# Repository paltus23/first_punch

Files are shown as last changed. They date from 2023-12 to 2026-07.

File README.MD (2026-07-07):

This project is intedent to sinmplify start teaching electronics for musical sysntesizers. 

I've already assempled and tested versions 1 and 1.1. 
Version 1.1 works fine but have two issues.
* You should cut track which connects gnd and pin 1 of RV10. Then you should solder small wire between RV10 pin 1 and Vref node.
* There is wrong ploarity of power supply

To use project install Kode Mono font.

There is few photos of ready device v1.1
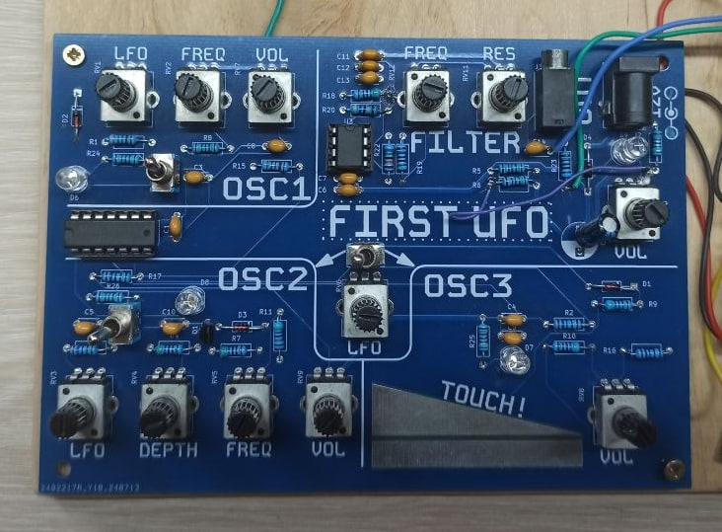
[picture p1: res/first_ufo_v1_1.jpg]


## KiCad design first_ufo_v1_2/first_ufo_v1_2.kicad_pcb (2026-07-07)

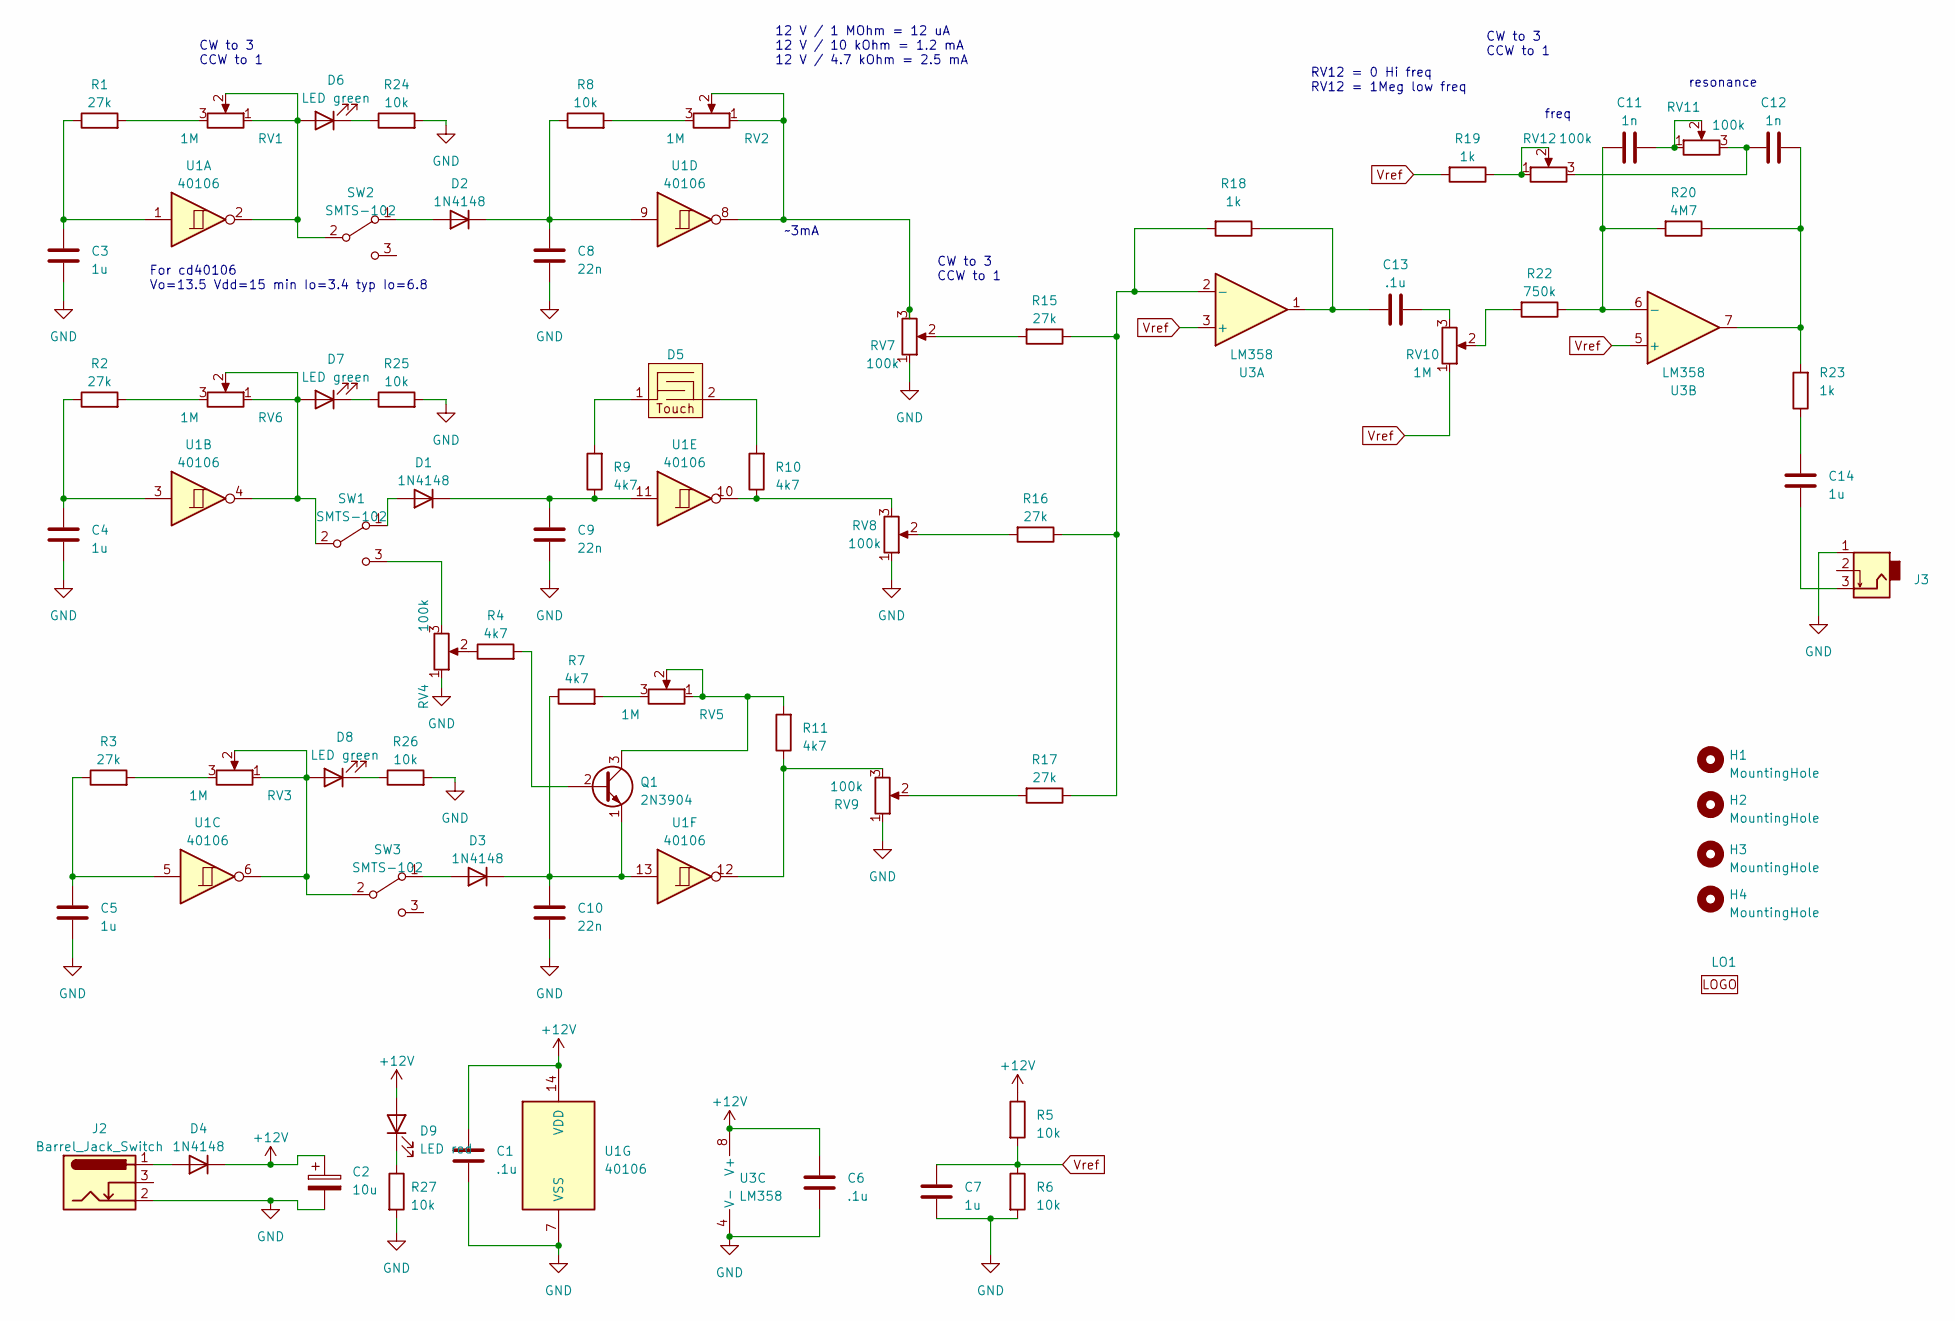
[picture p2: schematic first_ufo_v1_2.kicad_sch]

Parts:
C1, C6, C13: .1u; C_Disc_D4.3mm_W1.9mm_P5.00mm
C2: 10u; CP_Radial_D8.0mm_P5.00mm
C3, C4, C5, C7, C14: 1u; C_Disc_D4.3mm_W1.9mm_P5.00mm
C8, C9, C10: 22n; C_Disc_D4.3mm_W1.9mm_P5.00mm
C11, C12: 1n; C_Disc_D4.3mm_W1.9mm_P5.00mm
D1, D2, D3, D4: 1N4148; D_DO-35_SOD27_P10.16mm_Horizontal
D5: tactile pad triangle_1
D6, D7, D8: LED green; LED_D5.0mm
D9: LED red; LED_D5.0mm
H1, H2, H3, H4: MountingHole; MountingHole_3.2mm_M3
J2: Barrel_Jack_Switch; BarrelJack_Wuerth_6941xx301002
J3: PJ-316
LO1: Polarity_Center_Positive_3mm_SilkScreen
Q1: 2N3904; TO-92Flat
R1, R2, R3, R15, R16, R17: 27k; R_Axial_DIN0207_L6.3mm_D2.5mm_P10.16mm_Horizontal
R4, R7, R9, R10, R11: 4k7; R_Axial_DIN0207_L6.3mm_D2.5mm_P10.16mm_Horizontal
R5, R6, R8, R24, R25, R26, R27: 10k; R_Axial_DIN0207_L6.3mm_D2.5mm_P10.16mm_Horizontal
R18, R19, R23: 1k; R_Axial_DIN0207_L6.3mm_D2.5mm_P10.16mm_Horizontal
R20: 4M7; R_Axial_DIN0207_L6.3mm_D2.5mm_P10.16mm_Horizontal
R22: 750k; R_Axial_DIN0207_L6.3mm_D2.5mm_P10.16mm_Horizontal
RV1, RV2, RV3, RV5, RV6, RV10: 1M; Potentiometer_Bourns_PTV09A-1_Single_Vertical
RV4, RV7, RV8, RV9, RV11, RV12: 100k; Potentiometer_Bourns_PTV09A-1_Single_Vertical
SW1, SW2, SW3: SMTS-102
U1: 40106; DIP-14_W7.62mm
U3: LM358; DIP-8_W7.62mm

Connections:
+12V: C1.1, C2.1, C6.1, D4.1 (K), D9.2 (A), R5.1, U1.14 (VDD), U3.8 (V+)
GND: C1.2, C2.2, C3.2, C4.2, C5.2, C6.2, C7.2, C8.2, C9.2, C10.2, J2.2, J3.1, R6.2, R24.2, R25.2, R26.2, R27.2, RV4.1, RV7.1, RV8.1, RV9.1, U1.7 (VSS), U3.4 (V-)
unnamed: C3.1, R1.1, U1.1
unnamed: C4.1, R2.1, U1.3
unnamed: C5.1, R3.1, U1.5
unnamed: C11.2, RV11.1, RV11.2
unnamed: C12.1, RV11.3, RV12.3
unnamed: C12.2, R20.1, R23.2, U3.7
unnamed: C13.1, R18.1, U3.1
unnamed: C13.2, RV10.3
unnamed: C14.1, J3.3
unnamed: C14.2, R23.1
unnamed: D1.2 (A), SW1.1 (A)
unnamed: C9.1, D1.1 (K), R9.1, U1.11
unnamed: D2.2 (A), SW2.1 (A)
unnamed: C8.1, D2.1 (K), R8.1, U1.9
unnamed: D3.2 (A), SW3.1 (A)
unnamed: C10.1, D3.1 (K), Q1.1 (E), R7.1, U1.13
unnamed: D4.2 (A), J2.1
unnamed: D5.1, R9.2
unnamed: D5.2, R10.2
unnamed: D6.2 (A), RV1.1, RV1.2, SW2.2 (B), U1.2
unnamed: D6.1 (K), R24.1
unnamed: D7.2 (A), RV6.1, RV6.2, SW1.2 (B), U1.4
unnamed: D7.1 (K), R25.1
unnamed: D8.2 (A), RV3.1, RV3.2, SW3.2 (B), U1.6
unnamed: D8.1 (K), R26.1
unnamed: D9.1 (K), R27.1
unnamed: Q1.2 (B), R4.2
unnamed: Q1.3 (C), R11.2, RV5.1, RV5.2
unnamed: R1.2, RV1.3
unnamed: R2.2, RV6.3
unnamed: R3.2, RV3.3
unnamed: R4.1, RV4.2
unnamed: R7.2, RV5.3
unnamed: R8.2, RV2.3
unnamed: R10.1, RV8.3, U1.10
unnamed: R11.1, RV9.3, U1.12
unnamed: R15.2, RV7.2
unnamed: R16.2, RV8.2
unnamed: R17.2, RV9.2
unnamed: R19.1, RV12.1, RV12.2
unnamed: R22.2, RV10.2
unnamed: RV2.1, RV2.2, RV7.3, U1.8
unnamed: RV4.3, SW1.3 (C)
unnamed: R15.1, R16.1, R17.1, R18.2, U3.2 (-)
unnamed: C11.1, R20.2, R22.1, U3.6 (-)
Vref: C7.1, R5.2, R6.1, R19.2, RV10.1, U3.3 (+), U3.5 (+)

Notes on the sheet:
RV12 = 0 Hi freq RV12 = 1Meg low freq
resonance
CW to 3 CCW to 1
12 V / 1 MOhm = 12 uA 12 V / 10 kOhm = 1.2 mA 12 V / 4.7 kOhm = 2.5 mA
~3mA
For cd40106 Vo=13.5 Vdd=15 min Io=3.4 typ Io=6.8
freq

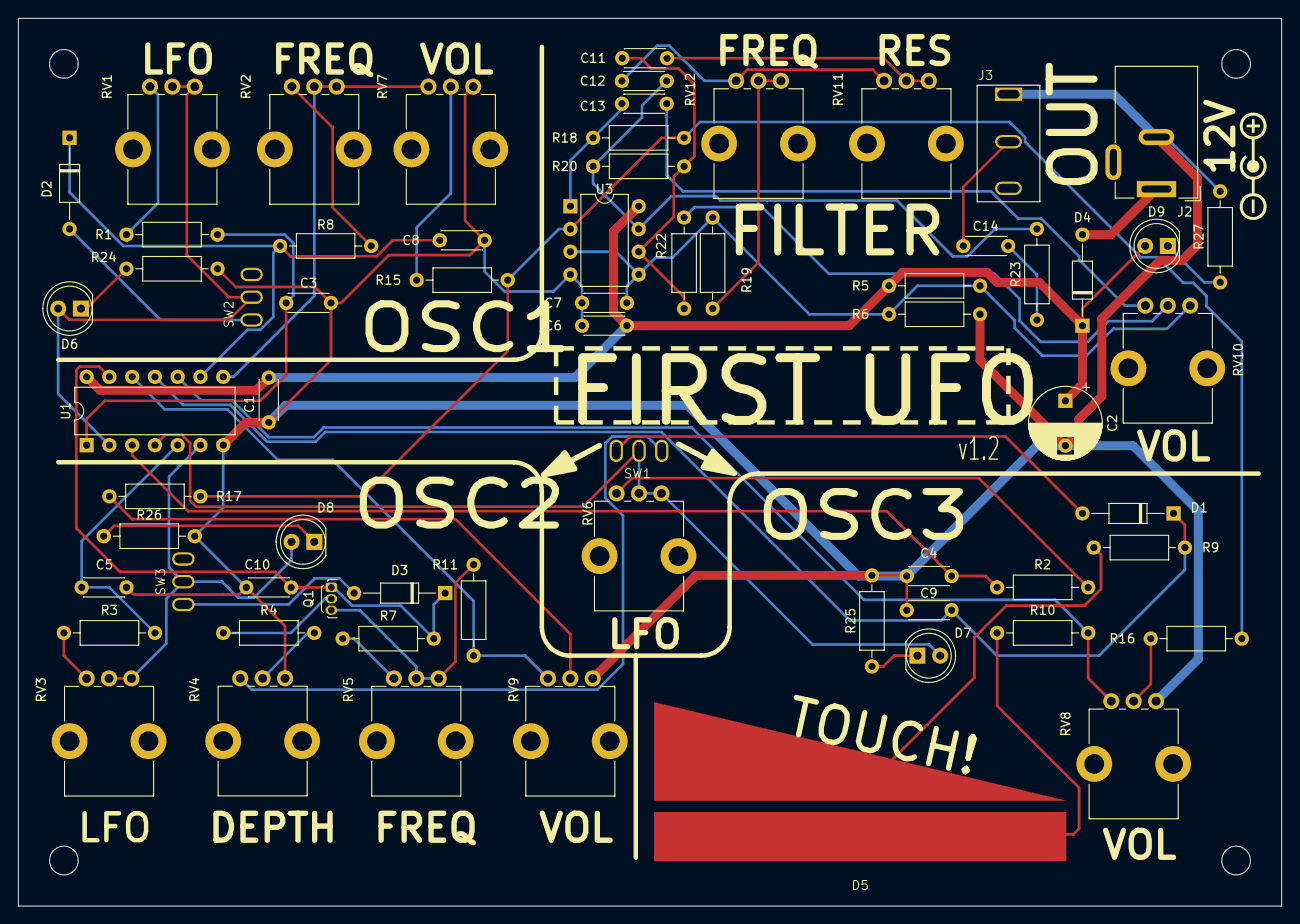
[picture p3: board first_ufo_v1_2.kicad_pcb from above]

Board: 2 copper layers, 141.0 x 99.1 mm, 71 parts (0 on the bottom side), 48 nets.

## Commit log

2023-12-14 Finish circuit and pcb
    [first_punch.kicad_pcb, first_punch.kicad_sch]
2023-12-14 add paints move ref resistors
    [first_punch.kicad_pcb]
2023-12-14 change AudioJack to PJ-316 Separate leds into green and red
    [first_punch.kicad_sch]
2023-12-14 add mounting holes for M3 screws
    [first_punch.kicad_pcb]
2023-12-17 add text - Ver1 - symbol for power supply - title - text on rear
    [first_punch.kicad_pcb]
2024-01-30 add coments on sch
    [first_punch.kicad_sch]
2024-04-11 move to directory
    [first_punch.kicad_pcb, first_punch.kicad_sch]
2024-04-11 add v1_1
    [first_ufo_v1_1.kicad_pcb, first_ufo_v1_1.kicad_sch]
2024-04-13 edit R15 16 17 to 27k for do not affect on freq in max volume edit RV7 8 9 for better control of volume. coz it use volatge divider now change filter for better control and range fix adder circuit. m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
    [first_ufo_v1_1.kicad_sch]
2024-06-20 move lines
    [first_ufo_v1_1.kicad_pcb]
2024-06-25 many many changes
    [first_ufo_v1_1.kicad_pcb]
2026-07-07 change R18 to 1k. that needs for increase dynamic range in case of all oscs in high volume level
    [first_ufo_v1_1.kicad_sch]
2026-07-07 added .kicad_prl files to gitignore
2026-07-07 added pcb version 1.2
    [first_ufo_v1_2.kicad_pcb, first_ufo_v1_2.kicad_sch]
2026-07-07 changed R18 to 1k for better dynamic range in case of high volume level of three oscs added verison title on pcb
    [first_ufo_v1_2.kicad_pcb, first_ufo_v1_2.kicad_sch]
